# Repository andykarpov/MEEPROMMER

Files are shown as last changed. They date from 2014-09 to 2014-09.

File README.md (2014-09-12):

MEEPROMMER
==========

(E)EPROM programmer based on Arduino hardware

The MEEPROMMER is a combination of hardware and software that lets you read and write 
data from (and to) 28C256, 28C128, 28C64, 28C16 EEPROMS.

The Arduino firmware provides a serial interface with simple commands to transfer data 
between a host computer and an eeprom.

For the host computer a Java based GUI application is available that uses the RXTX 
library to interface the programmer.

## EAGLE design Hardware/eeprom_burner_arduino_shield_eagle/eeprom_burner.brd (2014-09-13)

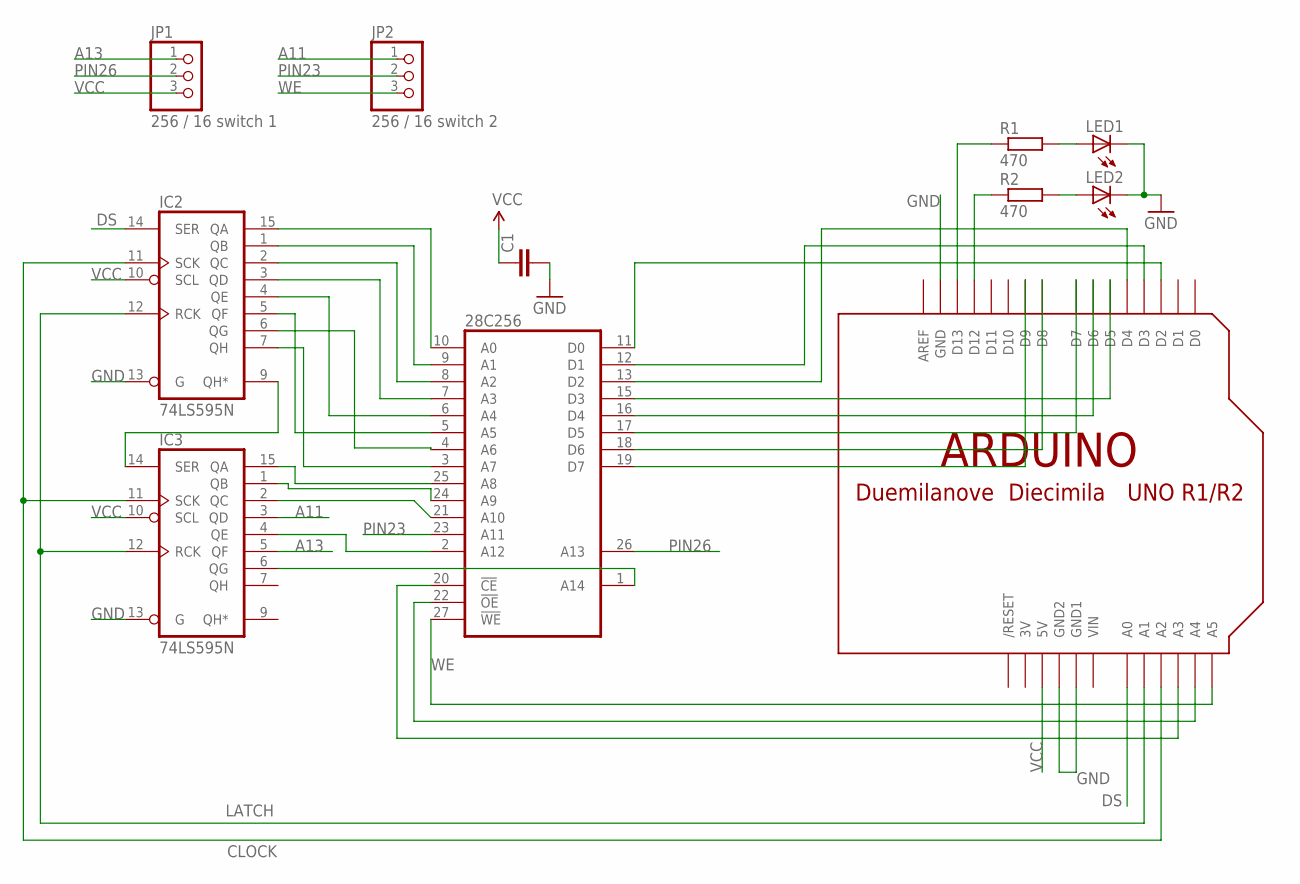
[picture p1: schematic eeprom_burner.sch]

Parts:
28C256: 2864; DIL28
C1: CAPPTH; CAP-PTH-SMALL
IC2, IC3: 74LS595N; DIL16
JP1: 256 / 16 switch 1; 1X03
JP2: 256 / 16 switch 2; 1X03
LED1, LED2: LED3MM
R1, R2: 470; 0204/7
U$1: ARDUINO-NODIM

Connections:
3V: U$1.3V
A11: IC3.3 (QD), JP2.1
A13: IC3.5 (QF), JP1.1
CLOCK: IC2.11 (SCK), IC3.11 (SCK), U$1.A2
DS: IC2.14 (SER), U$1.A0
GND: 28C256.14 (GND), C1.2, IC2.8 (GND), IC2.13 (G), IC3.8 (GND), IC3.13 (G), LED1.K (C), LED2.K (C), U$1.GND, U$1.GND1, U$1.GND2
LATCH: IC2.12 (RCK), IC3.12 (RCK), U$1.A1
unnamed: R2.1, U$1.D12
unnamed: 28C256.22 (!OE), U$1.A4
unnamed: 28C256.20 (!CE), U$1.A3
unnamed: 28C256.11 (D0), U$1.D2
unnamed: 28C256.12 (D1), U$1.D3
unnamed: 28C256.13 (D2), U$1.D4
unnamed: 28C256.15 (D3), U$1.D5
unnamed: 28C256.16 (D4), U$1.D6
unnamed: 28C256.17 (D5), U$1.D7
unnamed: 28C256.18 (D6), U$1.D8
unnamed: 28C256.19 (D7), U$1.D9
unnamed: 28C256.10 (A0), IC2.15 (QA)
unnamed: 28C256.9 (A1), IC2.1 (QB)
unnamed: 28C256.8 (A2), IC2.2 (QC)
unnamed: 28C256.7 (A3), IC2.3 (QD)
unnamed: 28C256.6 (A4), IC2.4 (QE)
unnamed: 28C256.5 (A5), IC2.5 (QF)
unnamed: 28C256.4 (A6), IC2.6 (QG)
unnamed: 28C256.3 (A7), IC2.7 (QH)
unnamed: IC2.9 (QH*), IC3.14 (SER)
unnamed: 28C256.25 (A8), IC3.15 (QA)
unnamed: 28C256.24 (A9), IC3.1 (QB)
unnamed: 28C256.21 (A10), IC3.2 (QC)
unnamed: R1.1, U$1.D13
unnamed: 28C256.2 (A12), IC3.4 (QE)
unnamed: LED1.A, R1.2
unnamed: 28C256.1 (A14), IC3.6 (QG)
unnamed: LED2.A, R2.2
PIN23: 28C256.23 (A11), JP2.2
PIN26: 28C256.26 (A13), JP1.2
VCC: 28C256.28 (VCC), C1.1, IC2.10 (SCL), IC2.16 (VCC), IC3.10 (SCL), IC3.16 (VCC), JP1.3, U$1.5V
VIN: U$1.VIN
WE: 28C256.27 (!WE), JP2.3, U$1.A5

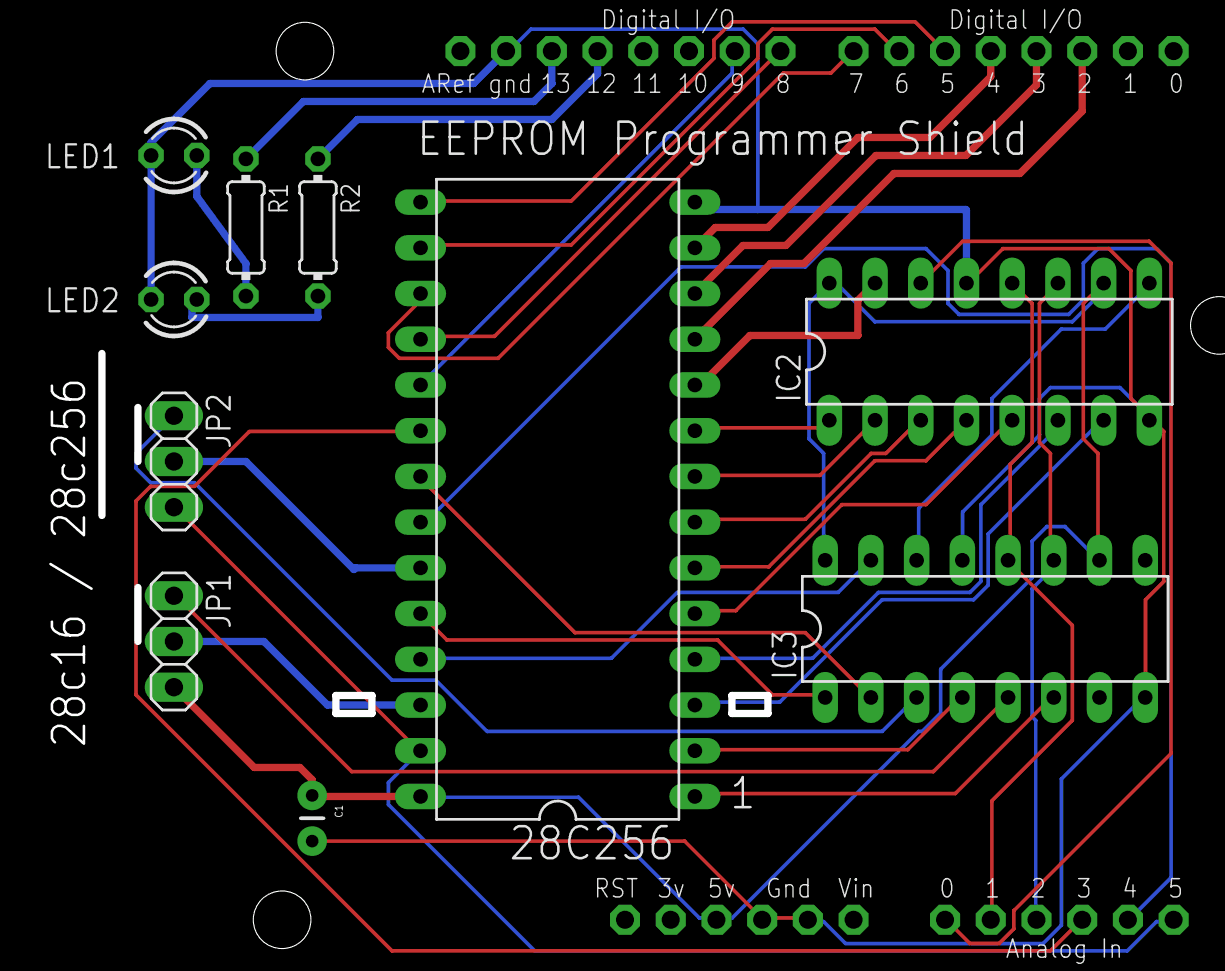
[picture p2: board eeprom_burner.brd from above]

Board: 2 copper layers, 11 parts (0 on the bottom side), 38 nets.

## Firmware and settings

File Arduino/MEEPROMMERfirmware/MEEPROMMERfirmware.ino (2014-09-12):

/**
 * ** Arduino EEPROM programmer **
 *
 * This sketch can be used to read and write data to a
 * AT28C16, AT28C64, AT28C256 parallel EEPROM
 *
 **/

#define VERSIONSTRING "MEEPROMMER MOD, CMD:A,R,r,w,W,V,C,E,P,p"

#define READ_DELAY 1 // uS
#define WRITE_DELAY 15 // mS

// eeprom stuff
// define the IO lines for the data - bus
#define D0 2
#define D1 3
#define D2 4
#define D3 5
#define D4 6
#define D5 7
#define D6 8
#define D7 9

// shiftOut part
#define DS     A0
#define LATCH  A1
#define CLOCK  A2

// define the IO lines for the eeprom control
#define CE     A3
#define OE     A4
#define WE     A5

#define LED_WRITE 13
#define LED_READ 12

//a buffer for bytes to burn
#define BUFFERSIZE 1024
byte buffer[BUFFERSIZE];
//command buffer for parsing commands
#define COMMANDSIZE 32
char cmdbuf[COMMANDSIZE];
 
unsigned int startAddress,endAddress;
unsigned int lineLength,dataLength;

#define CHIP28C64 0
#define CHIP28C128 1
#define CHIP28C256 2
#define CHIP28C512 3
#define CHIP28C16 4
#define CHIP28C32 5

unsigned int chipType;

//define COMMANDS
#define NOCOMMAND    0
#define VERSION      1
#define SET_ADDRESS  2

#define READ_HEX    10
#define READ_BIN    11
#define READ_ITL    12
 
#define WRITE_HEX   20
#define WRITE_BIN   21
#define WRITE_ITL   22
 
#define CHIP_TYPE   30
#define CHIP_ERASE  31

/****************************************************************
 *
 *  CONTROL and DATA functions
 *
 ****************************************************************/
 
// switch IO lines of databus to INPUT state
void data_bus_input() {
  pinMode(D0, INPUT);
  pinMode(D1, INPUT);
  pinMode(D2, INPUT);
  pinMode(D3, INPUT);
  pinMode(D4, INPUT);
  pinMode(D5, INPUT);
  pinMode(D6, INPUT);
  pinMode(D7, INPUT);
}
 
//switch IO lines of databus to OUTPUT state
void data_bus_output() {
  pinMode(D0, OUTPUT);
  pinMode(D1, OUTPUT);
  pinMode(D2, OUTPUT);
  pinMode(D3, OUTPUT);
  pinMode(D4, OUTPUT);
  pinMode(D5, OUTPUT);
  pinMode(D6, OUTPUT);
  pinMode(D7, OUTPUT);
}
 
//set databus to input and read a complete byte from the bus
//be sure to set data_bus to input before
byte read_data_bus()
{
  return ((digitalRead(D7) << 7) |
    (digitalRead(D6) << 6) |
    (digitalRead(D5) << 5) |
    (digitalRead(D4) << 4) |
    (digitalRead(D3) << 3) |
    (digitalRead(D2) << 2) |
    (digitalRead(D1) << 1) |
    digitalRead(D0));
}
 
//write a byte to the data bus
//be sure to set data_bus to output before
inline void write_data_bus(byte data)
{
  digitalWrite(D0, data & 1);
  digitalWrite(D1, data & 2);
  digitalWrite(D2, data & 4);
  digitalWrite(D3, data & 8);
  digitalWrite(D4, data & 16);
  digitalWrite(D5, data & 32);
  digitalWrite(D6, data & 64);
  digitalWrite(D7, data & 128);
}

//shift out the given address to the 74hc595 registers
inline void set_address_bus(unsigned int address)
{
  int addrlo = address & 0xFF;
  int addrhi = (address >> 8) & 0xFF;
  digitalWrite(LATCH, LOW);
  shiftOut(DS, CLOCK, MSBFIRST, addrhi);
  shiftOut(DS, CLOCK, MSBFIRST, addrlo);
  digitalWrite(LATCH, HIGH);
}

//short function to set the OE(output enable line of the eeprom)
// attention, this line is LOW - active
inline void set_oe (byte state)
{
  digitalWrite(OE, state);
}
 
//short function to set the CE(chip enable line of the eeprom)
// attention, this line is LOW - active
inline void set_ce (byte state)
{
  digitalWrite(CE, state);
}
 
//short function to set the WE(write enable line of the eeprom)
// attention, this line is LOW - active
inline void set_we (byte state)
{
  digitalWrite(WE, state);
}

//short function to set up the programmer for reading
void read_start() {
  digitalWrite(LED_READ, HIGH);
  //set databus for reading
  data_bus_input();
  //enable chip select
  set_ce(LOW);
  //disable write
  set_we(HIGH);
  //enable output
  set_oe(LOW);
}

//short function to stop reading
void read_end() {
  //disable output
  set_oe(HIGH);
  //disable chip select
  set_ce(HIGH);
  digitalWrite(LED_READ, LOW);
}  

//highlevel function to read a byte from a given address
inline byte read_byte(unsigned int address)
{
  //set address bus
  set_address_bus(address);
  delayMicroseconds(1);
  //read data
  return read_data_bus();
}

//flag set if we are on the first write pass
boolean firstWritePass = true;
 
//short function to set up the programmer for writing
void write_start() {
  digitalWrite(LED_WRITE, HIGH);
  firstWritePass = true;
  //first disable output
  set_oe(HIGH);
  //disable write
  set_we(HIGH);
  //set databus to output
  data_bus_output();
}

//short function to stop writing
void write_end() {
  //set databus to input
  data_bus_input();
  digitalWrite(LED_WRITE, LOW);
}

//highlevel function to write a byte to a given address
inline boolean fast_write(unsigned int address, byte data)
{
  static unsigned int lastAddress = 0;
  static byte lastData = 0;
  
  //this function uses /DATA polling to get the end of the
  //page write cycle. This is much faster than waiting 10ms

  //enable chip select
  set_ce(LOW);
  
  /*if (!firstWritePass) {
    unsigned long startTime = millis();

    //poll data until data matches
    data_bus_input();
    set_oe(LOW);

    while(lastData != read_data_bus()) {
      //set timeout here longer than JBurn timeout
      if (millis() - startTime > 3000) return false;
    }
    
    set_oe(HIGH);
    delayMicroseconds(1);
    data_bus_output();
  }*/
  
  //set address and data for write
  set_address_bus(address);
  delayMicroseconds(1);
  write_data_bus(data);
  delayMicroseconds(1);
 
  //strobe write
  set_we(LOW);
  delay(WRITE_DELAY);
  set_we(HIGH);
  //disable chip select
  set_ce(HIGH);

  lastAddress = address;
  lastData = data;
  firstWritePass = false;

  return true;
}

/*************************************************
 *
 * COMMAND and PARSING functions
 *
 *************************************************/
 
//waits for a string submitted via serial connection
//returns only if linebreak is sent or the buffer is filled
void readCommand() {
  //first clear command buffer
  for(int i=0; i< COMMANDSIZE;i++) cmdbuf[i] = 0;
  //initialize variables
  char c = ' ';
  int idx = 0;
  //now read serial data until linebreak or buffer is full
  do {
    if(Serial.available()) {
      c = Serial.read();
      cmdbuf[idx++] = c;
    }
  }
  while (c != '\n' && idx < (COMMANDSIZE)); //save the last '\0' for string end
  //change last newline to '\0' termination
  cmdbuf[idx - 1] = 0;
}
 
//parse the given command by separating command character and parameters
//at the moment only 5 commands are supported
byte parseCommand() {
  //set ',' to '\0' terminator (command string has a fixed strucure)
  //first string is the command character
  cmdbuf[1]  = 0;
  //second string is startaddress (4 bytes)
  cmdbuf[6]  = 0;
  //third string is endaddress (4 bytes)
  cmdbuf[11] = 0;
  //fourth string is length (2 bytes)
  cmdbuf[14] = 0;
  startAddress=hexWord((cmdbuf+2));
  dataLength=hexWord((cmdbuf+7));
  lineLength=hexByte(cmdbuf+12);
  byte retval = 0;
  switch(cmdbuf[0]) {
  case 'A':
    retval = SET_ADDRESS;
    break;
  case 'R':
    retval = READ_HEX;
    break;
  case 'r':
    retval = READ_BIN;
    break;
  case 'W':
    retval = WRITE_HEX;
    break;
  case 'w':
    retval = WRITE_BIN;
    break;
  case 'V':
    retval = VERSION;
    break;
  case 'C':
    retval = CHIP_TYPE;
    break;
  case 'E':
    retval = CHIP_ERASE;
    break;
  default:
    retval = NOCOMMAND;
    break;
  }
 
  return retval;
}
 
/************************************************************
 * convert a single hex digit (0-9,a-f) to byte
 * @param char c single character (digit)
 * @return byte represented by the digit
 ************************************************************/
inline byte hexDigit(char c)
{
  //use lookup table for char to hex conversion
  const char chartohex[] = {0, 1, 2, 3, 4, 5, 6, 7, 8, 9,
                    0, 0, 0, 0, 0, 0, 0,
                    10, 11, 12, 13, 14, 15 };
  return chartohex[c - '0'];
}
 
/************************************************************
 * convert a hex byte (00 - ff) to byte
 * @param c-string with the hex value of the byte
 * @return byte represented by the digits
 ************************************************************/
byte hexByte(char* a)
{
  return ((hexDigit(a[0]) << 4) | hexDigit(a[1]));
}
 
/************************************************************
 * convert a hex word (0000 - ffff) to unsigned int
 * @param c-string with the hex value of the word
 * @return unsigned int represented by the digits
 ************************************************************/
unsigned int hexWord(char* data) {
  return ((hexDigit(data[0]) << 12) |
    (hexDigit(data[1]) << 8) |
    (hexDigit(data[2]) << 4) |
    (hexDigit(data[3])));
}
 
 
/************************************************
 *
 * INPUT / OUTPUT Functions
 *
 *************************************************/
 
 
/**
 * read a data block from eeprom and write out a hex dump
 * of the data to serial connection
 * @param from       start address to read fromm
 * @param to         last address to read from
 * @param linelength how many hex values are written in one line
 **/
void read_block(unsigned int from, unsigned int to, int linelength)
{
  //count the number fo values that are already printed out on the
  //current line
  int               outcount = 0;
  //loop from "from address" to "to address" (included)
  unsigned int address = from;
  read_start();
  do {
    if (outcount == 0) {
      //print out the address at the beginning of the line
      Serial.println();
      Serial.print("0x");
      printAddress(address);
      Serial.print(" : ");
    }
    //print data, separated by a space
    byte data = read_byte(address);
    printByte(data);
    Serial.print(" ");
    outcount = (++outcount % linelength);
  } while (address++ != to);
  read_end();

  //print a newline after the last data line
  Serial.println();
 
}
 
/**
 * read a data block from eeprom and write out the binary data
 * to the serial connection
 * @param from       start address to read fromm
 * @param to         last address to read from
 **/
void read_binblock(unsigned int from, unsigned int to) {
  unsigned int address = from;

  read_start();
  do {
    Serial.write(read_byte(address));
  } while (address++ != to);
  read_end();

  //print out an additional 0-byte as success return code
  Serial.print('\0');
}  
 
/**
 * write a data block to the eeprom
 * @param address  startaddress to write on eeprom
 * @param buffer   data buffer to get the data from
 * @param len      number of bytes to be written
 **/
void write_block(unsigned int address, byte* buffer, int len) {
  write_start();
  for (unsigned int i = 0; i < len; i++) {
    if (fast_write(address++, *buffer++) == false)
      break;
  }
  write_end();
}
 
/**
 * erase entire chip
 **/
void chip_erase() {
  int last_address = 0;
  switch (chipType) {
    case CHIP28C16:
      last_address = 2048;
    break;
    case CHIP28C32:
      last_address = 4096;
    break;
    case CHIP28C64:
      last_address = 8192;
    break;
    case CHIP28C128:
      last_address = 16384;
    break;
    case CHIP28C256:
      last_address = 32768;
    break;
    case CHIP28C512:
      last_address = 65536;
    break;
  }
  write_start();
  for (unsigned int addr = 0; addr < last_address; addr++) {
    if (fast_write(addr, 0xFF) == false)
      break;
  }
  write_end();
}
 
/**
 * print out a 16 bit word as 4 character hex value
 **/
void printAddress(unsigned int address) {
  if(address < 0x0010) Serial.print("0");
  if(address < 0x0100) Serial.print("0");
  if(address < 0x1000) Serial.print("0");
  Serial.print(address, HEX);
 
}
 
/**
 * print out a byte as 2 character hex value
 **/
void printByte(byte data) {
  if(data < 0x10) Serial.print("0");
  Serial.print(data, HEX);  
}
 
 
 
 
 
/************************************************
 *
 * MAIN
 *
 *************************************************/
void setup() {
  //default to 28C64 for backward JBurn compatability
  chipType = CHIP28C64;

  //define the shiuftOut Pins as output
  pinMode(DS, OUTPUT);
  pinMode(LATCH, OUTPUT);
  pinMode(CLOCK, OUTPUT);
 
  //define the EEPROM Pins as output
  // take care that they are HIGH
  digitalWrite(OE, HIGH);
  pinMode(OE, OUTPUT);
  digitalWrite(CE, HIGH);
  pinMode(CE, OUTPUT);
  digitalWrite(WE, HIGH);
  pinMode(WE, OUTPUT);
  
  pinMode(LED_WRITE, OUTPUT);
  pinMode(LED_READ, OUTPUT);
  
  //set speed of serial connection
  //on Leonardo this is noop
  Serial.begin(115200);
//  Serial.begin(460800);
//Serial.begin(9600);
}
 
/**
 * main loop, that runs invinite times, parsing a given command and
 * executing the given read or write requestes.
 **/
void loop() {
  readCommand();
  byte cmd = parseCommand();
  int bytes = 0;
  switch(cmd) {
  case SET_ADDRESS:
    // Set the address bus to an arbitrary value.
    // Useful for debugging shift-register wiring, byte-order.
    // e.g. A,00FF
    Serial.print("Setting address bus to 0x");
    Serial.println(cmdbuf + 2);
    set_address_bus(startAddress);
    break;
  case READ_HEX:
    //set a default if needed to prevent infinite loop
    if(lineLength==0) lineLength=32;
    endAddress = startAddress + dataLength -1;
    read_block(startAddress,endAddress,lineLength);
    Serial.println('%');
    break;
  case READ_BIN:
    endAddress = startAddress + dataLength -1;
    read_binblock(startAddress,endAddress);
    break;
  case READ_ITL:
    break;
  case WRITE_BIN:
    //take care for max buffer size
    if(dataLength > 1024) dataLength = 1024;
    endAddress = startAddress + dataLength -1;
    while(bytes < dataLength) {
      if(Serial.available()) buffer[bytes++] = Serial.read();
    }    
    write_block(startAddress,buffer,dataLength);
    delayMicroseconds(150);
    Serial.println('%');
    break;
  case WRITE_HEX:
    break;
  case WRITE_ITL:
    break;
  case VERSION:
    Serial.println(VERSIONSTRING);
    break;
  case CHIP_TYPE:
    chipType = startAddress;
    break;
  case CHIP_ERASE:
    chip_erase();
    Serial.println('%');
    break;
  default:
    break;    
  }
}

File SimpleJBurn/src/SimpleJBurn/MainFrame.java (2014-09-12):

/*
 * To change this template, choose Tools | Templates
 * and open the template in the editor.
 */
package SimpleJBurn;

import gnu.io.CommPortIdentifier;
import java.awt.Color;
import java.awt.Cursor;
import java.awt.Dimension;
import java.awt.Toolkit;
import java.beans.PropertyChangeEvent;
import java.beans.PropertyChangeListener;
import java.io.BufferedWriter;
import java.io.File;
import java.io.FileInputStream;
import java.io.FileOutputStream;
import java.io.IOException;
import java.io.OutputStreamWriter;
import java.util.HashSet;
import java.util.Iterator;
import javax.swing.JFileChooser;
import javax.swing.JOptionPane;
import javax.swing.SwingWorker;
import javax.swing.text.AttributeSet;
import javax.swing.text.BadLocationException;
import javax.swing.text.SimpleAttributeSet;
import javax.swing.text.StyleConstants;
import javax.swing.text.StyleContext;
import javax.swing.text.StyledDocument;
import javax.swing.UIManager;

/**
 *
 * @author mario
 */
public class MainFrame extends javax.swing.JFrame implements PropertyChangeListener {

    static private final String revision = "$Revision: 1.6 $";
    static private final String date = "$Date: 2013/07/31 13:00:00 $";
    //used to end a line in the output window
    static private final String newline = "\n";
    private static final String[] EEPROMTYPES = {"28C64  (8KiB) ", "28C128 (16KiB)", "28C256 (32KiB)", "27SF512 (64KiB)", "27C16 (2KiB)"};
    private static final String[] OFFSETS = {"-----", " 2KiB", " 4KiB", " 8KiB", "16KiB", "24KiB", "32KiB", "48KiB"};
    private ReadTask readTask;
    private WriteTask writeTask;
    MySerial mySerial = new MySerial();
    String selectedComPort;
    byte[] data = new byte[65536];
    byte[] eeprom = new byte[65536];
    int maxAddress = 8192;
    int chipType = 0;
    int offset = 0;
    long filesize = 0;
    int sequenceCtr = 0;
    boolean failure = false;
    
    enum Action {
        DIFF, READ, BLANK
    };

    class ReadTask extends SwingWorker<Void, Void> {

        public int done = 0;
        long start, end = 0;
        int readProgress = 0;
        
        Action action;

        public ReadTask(Action a) {
            this.action = a;
            statusLabel.setText("");
            progressBar.setValue(0);
            setCursor(Cursor.getPredefinedCursor(Cursor.WAIT_CURSOR));
        }

        /*
         * Main task. Executed in background thread.
         */
        @Override
        public Void doInBackground() {
            //check if eeprom should be read or written
            try {
                failure = false;
                //remove old data from input stream to prevent them "poisening" our
                //data
                mySerial.in.skip(mySerial.in.available());
                //take time to read the eeprom
                start = System.currentTimeMillis();
                BufferedWriter bw = new BufferedWriter(new OutputStreamWriter(mySerial.out));
                String line = "";

                appendToLog("sending command." + newline);
                bw.write("r,0000," + Utility.wordToHex(maxAddress) + ",20" + newline);
                bw.flush();
                appendToLog("command sent." + newline);
                appendToLog("trying to read." + newline);
                int counter = 0, c;
                do {
                    if (mySerial.in.available()>0) {
                        c = mySerial.in.read();
                        if (c == -1) throw new Exception("Communication timeout");
                        eeprom[counter++] = (byte) c;
                        if (counter % 100 == 0) {
                            readProgress = 100 * counter / maxAddress;
                            setProgress(readProgress);
                        }
                    }
                } while (counter < maxAddress);
                end = System.currentTimeMillis();
                setProgress(100);


            } catch (Exception e) {
                appendToLog("Error: " + e.getMessage() + newline);
                failure = true;
            }

            /**
             * Random random = new Random(); int progress = 0; int steps = 100 /
             * (maxAddress / 1024); //Initialize progress property.
             * setProgress(0); for (int i = offset; i < maxAddress; i += 1024) {
             * try { Thread.sleep(random.nextInt(300)); } catch
             * (InterruptedException ignore) { } progress = i * 100 /
             * maxAddress; done = i; setProgress(Math.min(progress, 100)); }
             * setProgress(100); return null; *
             */
            return null;
        }

        /*
         * Executed in event dispatching thread
         */
        @Override
        public void done() {
            Toolkit.getDefaultToolkit().beep();
            verifyButton.setEnabled(true);
            blankButton.setEnabled(true);
            readButton.setEnabled(true);
            setCursor(null); //turn off the wait cursor
            appendToLog(maxAddress + " bytes read in " + (float) (end - start) / 1000
                    + " seconds " + newline);
            if (this.action == Action.DIFF) {
                appendToLog("Checking difference between loaded ROM file and data on EEPROM"
                        + newline);
                int byteCount = 0;
                //this.readEEPROM();
                for (int i = 0; i < filesize; i++) {
                    if (data[i] != eeprom[i + offset]) {
                        byteCount++;
                    }
                }
                appendToLog(filesize + " bytes checked from 0x" + Utility.wordToHex(offset)
                        + " to 0x" + Utility.wordToHex(offset + (int) filesize - 1) + ", " + byteCount
                        + " byte are different." + newline);
                if (!failure && byteCount == 0)
                    failure = false;
                else
                    failure = true;
            } else if (this.action == Action.BLANK) {
                int i, byteCount = 0;
                //this.readEEPROM();
                for (i = 0; i < maxAddress; i++) {
                    if (eeprom[i] != -1)
                        break;
                }
                if (i == maxAddress) {
                    appendToLog( "Blank check success! " + newline );
                    if (!failure) failure = false;
                } else {
                    appendToLog( "Blank check failed! " + newline );
                    failure = true;
                }
            }
            CheckSequence();
        }
    }

    class WriteTask extends SwingWorker<Void, Void> {

        public int done = 0;
        int len;
        int address;
        long start, end = 0;
        int writeProgress = 0;
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

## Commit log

2013-08-02 Fixed write data bit shift for Leonardo.
    Boost PWM now working on both UNO and Leonardo at 62kHz.
    [MEEPROMMERfirmware.ino]
2013-08-02 Add additional comments to Arduino sketch also make chartohex a const
2013-08-03 Fix potential bug for 28C page write
    [MEEPROMMERfirmware.ino]
2013-11-22 CMD list in version string corrected; matches parseCommand().
    [MEEPROMMERfirmware.ino]
2013-11-22 New 'A,0000' command sets address bus to given value.
    Useful for debugging shift-register wiring and the resulting address bus
    byte order.
    e.g. `A,00FF` should only set A0..A7 high.
2014-09-12 Added support for 27C16; Hotfixes to work on OSX 10.6 and old Arduinos
2014-09-13 updated board layout
    [eeprom_burner.brd, eeprom_burner.sch]

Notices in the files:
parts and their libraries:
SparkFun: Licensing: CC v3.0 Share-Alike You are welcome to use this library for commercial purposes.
